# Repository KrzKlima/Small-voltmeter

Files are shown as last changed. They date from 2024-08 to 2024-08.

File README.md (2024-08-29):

# Small-voltmeter
The project and all files in this repository are provided under CC BY-NC-SA 4.0 license.

This voltmeter is small (I mean, small), cute, fits on a breadboard and is powered from a 3v3 voltage supply. It even includes a Zener voltage regulator, but for larger supply voltages a dropper resistor is required (0402 resistors have weak power capabilities). The use of bubble display makes reading the voltage easy, despite the minute size of the digits. It uses ATTiny44A and MCP3421 ADC. The board size is 20.5mm by 10.5mm. The device is able to measure its own supply voltage, so no such problems occur as in ICL7107 circuits.

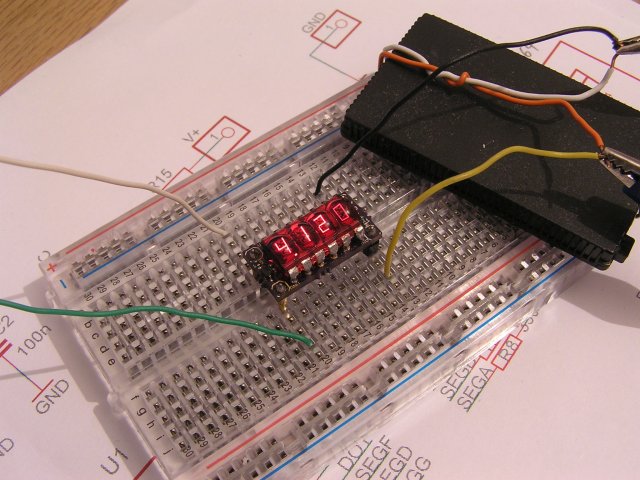
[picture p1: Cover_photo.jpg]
cover photo


The measurement ranges are the following:
1) -2V to 10V with the resolution of 1mV
2) outside the range 1), within -20 to 100V, with the resolution of 10mV
3) outside the ranges 1) and 2), within -200 to 200V, with the resolution of 100mV
(but you need to observe the safety issues with such high voltages)

Highlights:
- small form factor ~DIP16
- due to the low pin count of the MCU, I2C bus to the external ADC is multiplexed with display outputs - and it still works!
- differential input
- measures ground referenced voltages of both polarities

Two videos showing the operation of the multimeter are linked below.

SAMPLE VIDEO 1 (https://www.youtube.com/watch?v=5PMVABGqFHo "Small multimeter - video 1")
SAMPLE VIDEO 2 (https://www.youtube.com/watch?v=kH4eJVx0Qz0 "Small multimeter - video 2")

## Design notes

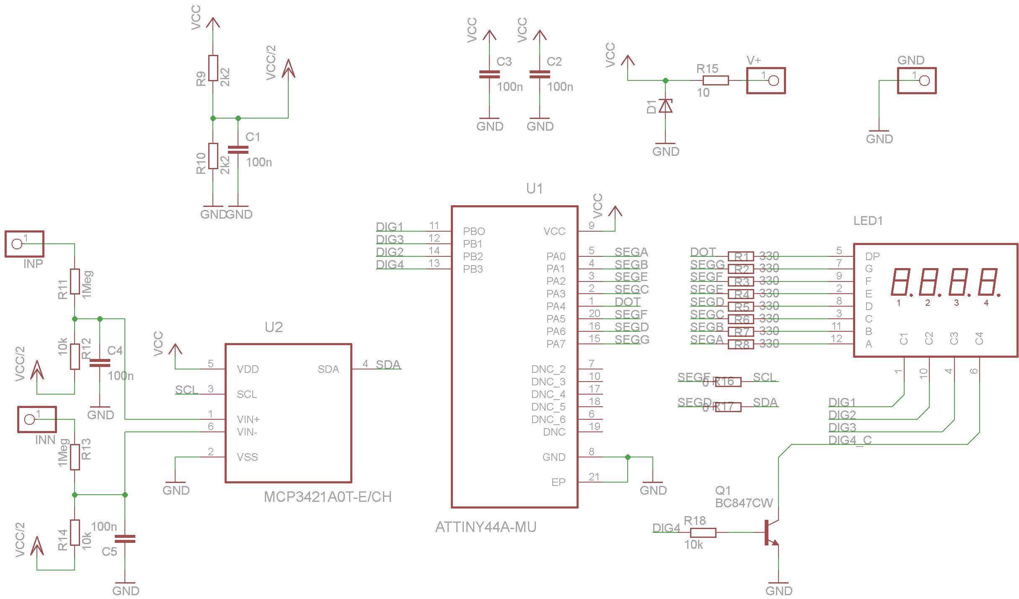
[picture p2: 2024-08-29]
PCB/maly_woltomierz_schemat.png

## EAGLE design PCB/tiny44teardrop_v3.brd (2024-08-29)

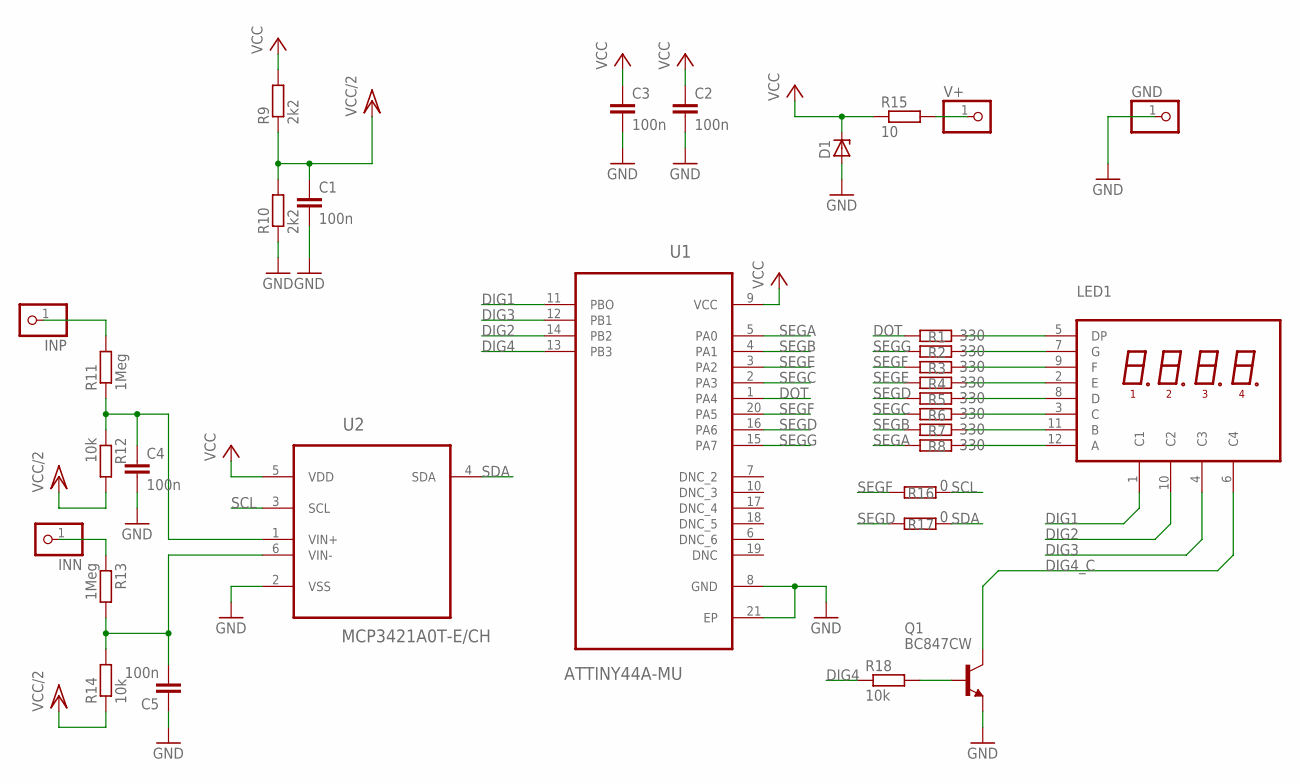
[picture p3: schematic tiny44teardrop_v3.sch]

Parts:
C1, C2, C3, C4, C5: 100n; C0603K
D1: BZX84CSMDBZT52C3V3S-7-F; SOD323-R
GND: PINHD-1X1; 1X01
INN: PINHD-1X1; 1X01
INP: PINHD-1X1; 1X01
LED1: 5082-7414
Q1: BC847CW; SOT323-BEC
R1, R2, R3, R4, R5, R6, R7, R8: 330; R0402
R9, R10: 2k2; R0402
R11, R13: 1Meg; R0603
R12, R14, R18: 10k; R0402
R15: 10; R0402
R16, R17: 0; R0402
U1: ATTINY44A-MU; QFN50P400X400X80-21N
U2: MCP3421A0T-E/CH; SOT95P270X145-6N
V+: PINHD-1X1; 1X01

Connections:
DIG1: LED1.1 (C1), U1.11 (PBO)
DIG2: LED1.10 (C2), U1.14 (PB2)
DIG3: LED1.4 (C3), U1.12 (PB1)
DIG4: R18.1, U1.13 (PB3)
DIG4_C: LED1.6 (C4), Q1.C
DOT: R1.1, U1.1 (PA4)
GND: C1.2, C2.2, C3.2, C4.2, C5.1, D1.A, GND.1, Q1.E, R10.1, U1.8 (GND), U1.21 (EP), U2.2 (VSS)
unnamed: LED1.5 (DP), R1.2
unnamed: LED1.7 (G), R2.2
unnamed: R15.2, V+.1
unnamed: LED1.2 (E), R4.2
unnamed: LED1.9 (F), R3.2
unnamed: LED1.3 (C), R6.2
unnamed: LED1.11 (B), R7.2
unnamed: LED1.12 (A), R8.2
unnamed: LED1.8 (D), R5.2
unnamed: INP.1, R11.2
unnamed: Q1.B, R18.2
unnamed: INN.1, R13.1
unnamed: C5.2, R13.2, R14.2, U2.6 (VIN-)
unnamed: C4.1, R11.1, R12.1, U2.1 (VIN+)
SCL: R16.1, U2.3 (SCL)
SDA: R17.1, U2.4 (SDA)
SEGA: R8.1, U1.5 (PA0)
SEGB: R7.1, U1.4 (PA1)
SEGC: R6.1, U1.2 (PA3)
SEGD: R5.1, R17.2, U1.16 (PA6)
SEGE: R4.1, U1.3 (PA2)
SEGF: R3.1, R16.2, U1.20 (PA5)
SEGG: R2.1, U1.15 (PA7)
VCC: C2.1, C3.1, D1.C, R9.2, R15.1, U1.9 (VCC), U2.5 (VDD)
VCC/2: C1.1, R9.1, R10.2, R12.2, R14.1

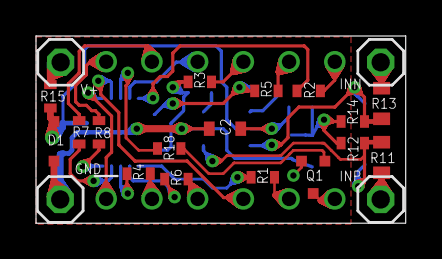
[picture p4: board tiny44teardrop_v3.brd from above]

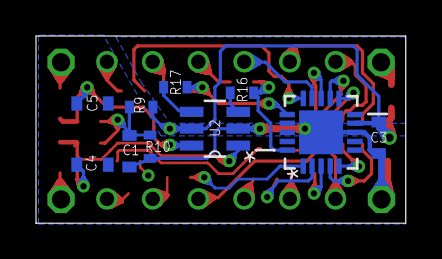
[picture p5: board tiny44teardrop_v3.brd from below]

Board: 2 copper layers, 20.5 x 10.4 mm, 32 parts (10 on the bottom side), 32 nets.

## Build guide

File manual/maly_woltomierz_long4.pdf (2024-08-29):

# Miniwoltomierz

### SQ3NQJ

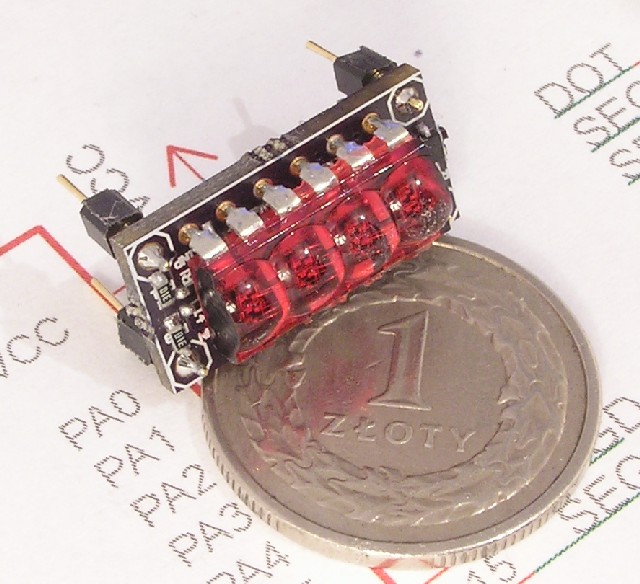
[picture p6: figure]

Układ służy do pomiaru napięcia, wykorzystuje niewielką liczbę komponentów i cechuje się niezwykle małymi rozmiarami. Zmierzoną wartość napięcia wyświetla za pomocą miniaturowych siedmiosegmentowych wyświetlaczy LED. Stopień podziału w dzielniku wejściowym jest zaprojektowany tak, aby prezentowany woltomierz można było wykorzystać do pomiaru napięć stałych w zakresie od -200V do +200V. Pomimo tego, ze względu na budowę urządzenia i bezpieczeństwo jego użytkowania zakres bezpiecznie mierzonych napięć jest mniejszy i ograniczony względami bezpieczeństwa użytkownika. Różnicowa impedancja wejściowa wynosi około 2MΩ.

Układ wykonany jest w technologii montażu powierzchniowego, wykorzystuje jedynie dwa układy scalone: mikrokontroler oraz przetwornik analogowo-cyfrowy. Pozostałe elementy to 1 tranzystor, dioda Zenera i rezystory oraz kondensatory.
Schemat blokowy układu przedstawiony jest na rysunku 1, a dokładny schemat ideowy przedstawiony jest na rysunku 3 na końcu dokumentu. Spis elementów zamieszczony jest w tabeli 1 na końcu dokumentu.

Rysunek 1. Schemat blokowy woltomierza.

Zastosowanie niewielkich elementów i ograniczenie ich liczby umożliwiło spektakularne zmniejszenie całości urządzenia do wymiarów 20,5mm na 10,5mm i wysokość, po zamontowaniu na płytce stykowej, 11mm. Widok projektu płytki przedstawiony jest na rysunku 8.
Na rysunku 2 pokazane jest urządzenie w trakcie pomiarów. Uwagę zwracają małe wymiary. Wyświetlacz jest czytelny nawet przy dużych kątach obserwacji.

dzielnik
rezystorowy

ADC

(MCP3421) | ATTiny44a | wyświetlacz LED

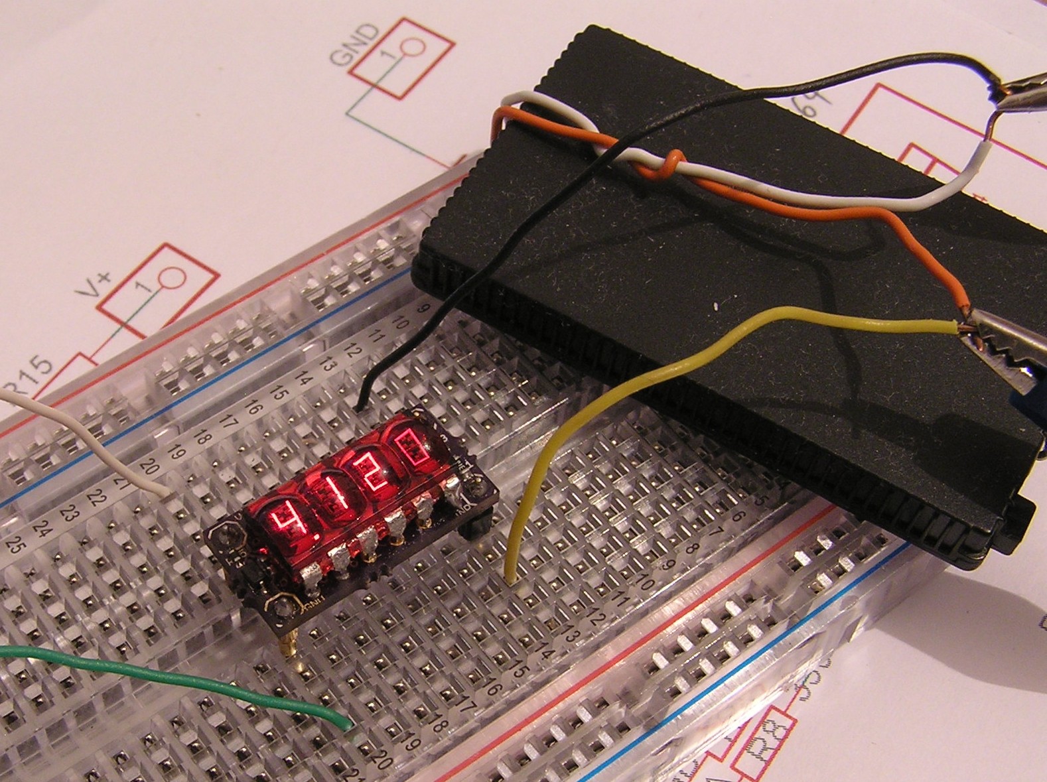
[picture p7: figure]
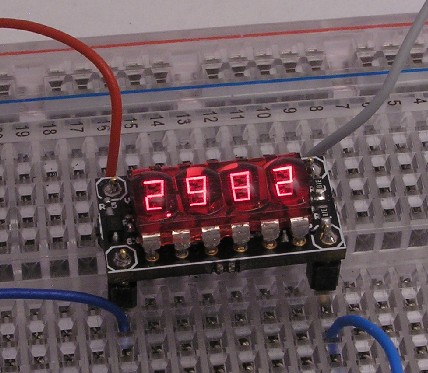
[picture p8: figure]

Rysunek 2. Woltomierz mierzący różne napięcia.

### Rozwiązania układowe

Woltomierz ma wejście różnicowe, umożliwia pomiar napięć zewnętrznych jak też własnego napięcia zasilania (przy dowolnej polaryzacji wejść). W układzie wykorzystywany jest przetwornik analogowo-cyfrowy o rozdzielczości 18 bitów, komunikujący się z mikrokontrolerem sterującym za pomocą magistrali I²C. Urządzenie pracuje poprawnie z układami MCP 3421 o dowolnym spośród 8 dostępnych adresów, ustawianych na etapie produkcji układu. Dzięki temu możliwe jest wykorzystanie dowolnej aktualnie dostępnej wersji tego przetwornika.
Ze względu na niewielką liczbę dostępnych wyprowadzeń, konieczne stało się wykorzystanie do podłączenia linii SDA i SCL interfejsu I²C wyprowadzeń używanych do sterowania wyświetlaczem. Jest to możliwe dzięki zapewnieniu poniższych warunków:
1. Transmisja odbywa się w czasie przerwy w wyświetlaniu danych na wyświetlaczu (wszystkie segmenty wszystkich cyfr są wtedy wygaszone) i nie jest przerywana aż do zakończenia transmisji.
2. Warunek startu i końca transmisji na liniach interfejsu występuje jedynie w chwilach rozpoczęcia i zakończenia transmisji I²C, a nie występuje w czasie wyświetlania danych na wyświetlaczu.

Wynik pomiaru wyświetlany jest na wyświetlaczu czteropozycyjnym bez dodatkowego znaku „minus”. Do wyświetlania znaku „minus” wykorzystywany jest jeden z segmentów wyświetlacza odpowiadającego „najstarszej” cyfrze. Takie rozwiązanie upraszcza konstrukcję i umożliwia wykorzystanie łatwiej dostępnych elementów, jednak ogranicza rozdzielczość wyświetlania dla wartości ujemnych. Zastosowane rozwiązanie umożliwia uzyskanie następujących rozdzielczości:

1) dla zakresu od -2V do 10V: 1mV
2) poza zakresem 1), dla zakresu od -20 do 100V: 10mV
3) poza zakresami 1) i 2), dla zakresu od -200 do 200V: 100mV

Układ zasilany jest napięciem 3,3V. Układ wyposażony jest w prosty stabilizator napięcia zasilania z diodą Zenera, zapewniający podstawowe zabezpieczenie przed zbyt wysokim napięciem zasilania, bądź odwrotnym podłączeniem napięcia zasilającego. Pobór prądu wynosi około 24mA – większość prądu zużywana jest przez wyświetlacz LED.
Aby umożliwić pomiar napięć o dowolnej polaryzacji, zastosowane zostało bardzo proste rozwiązanie, polegające na użyciu potencjału masy pozornej – elementy R9, R10, C1 – jako potencjału odniesienia dla dzielników wejściowych. Konsekwencją tego jest utrzymywanie potencjału spoczynkowego wejść woltomierza na poziomie zbliżonym do połowy napięcia zasilania mierzonym względem masy zasilania woltomierza. Jednak wysoka impedancja wejściowa woltomierza zmniejsza wpływ tego napięcia na badany układ.
Dziwić może obecność tranzystora Q1, okazał się on jednak niezbędny ze względu na znacznie mniejszą wydajność prądową bufora wyjściowego pinu PB3 (pracującego domyślnie jako nóżka RESET) w porównaniu z pozostałymi pinami mikrokontrolera.

### Oprogramowanie

W większości urządzeń zawierających układy programowalne, o funkcjonalności urządzenia decyduje w głównej mierze oprogramowanie. Podobnie jest w tym przypadku. Uproszczony schemat blokowy działania oprogramowania przedstawiony jest na rysunku 4.
Po rozpoczęciu działania urządzenia inicjalizowane są porty mikrokontrolera i wyszukiwany jest adres I²C przetwornika analogowo-cyfrowego, następnie dokonywane jest sprawdzenie, czy dokonana została poprawna kalibracja lub czy należy zresetować ustawienia kalibracyjne. W przypadku braku danych kalibracyjnych uruchamiana jest procedura kalibracji, opisana dalej. W przypadku odnalezienia w pamięci EEPROM poprawnych danych kalibracyjnych urządzenie przechodzi w tryb pomiaru napięcia. W nieskończonej pętli urządzenie cyklicznie pobiera dane z przetwornika, poddaje je odpowiednim przeliczeniom i umieszcza dane wynikowe w pamięci. Z pamięci dane te są z kolei pobierane przez procedurę obsługi wywoływanego około 500 razy na sekundę przerwania wyświetlającego wyniki pomiaru na czteropozycyjnym wyświetlaczu siedmiosegmentowym. Warto podkreślić, że na czas trwania komunikacji z przetwornikiem analogowo-cyfrowym, ze względu na fakt podwójnego wykorzystania linii danych i zegara I²C, przerwanie odpowiadające za obsługę wyświetlacza jest blokowane, aby nie zakłócić transferu danych.
Dla najniższego zakresu pomiarowego, charakteryzującego się największą rozdzielczością, zmieniane jest ustawienie wzmacniacza pomiarowego znajdującego się wewnątrz przetwornika analogowo-cyfrowego. Wzmocnienie ustawiane jest na 2V/V, zamiast wykorzystywanego w pozostałych zakresach 1V/V. Użycie wzmocnienia 2V/V jest niezbędne w celu zapewnienia faktycznej rozdzielczości woltomierza wynoszącej dla najniższego zakresu 1mV.

### Procedura kalibracji

Kalibracja przeprowadzana jest z wykorzystaniem zewnętrznego napięcia o wartości 10V. W przypadku wykrycia braku poprawnych wartości kalibracyjnych uruchamiana jest procedura kalibracji, w której program dokonuje wielokrotnego pomiaru podawanego napięcia i uśrednia wynik. Następnie sprawdzane jest, czy otrzymana wartość kalibracyjna mieści się w założonych granicach. Dzięki temu możliwe jest uniknięcie większości przypadków niepoprawnie przeprowadzonej kalibracji. Kalibracja przeprowadzana jest dla 2 różnych ustawień wzmacniacza o regulowanym wzmocnieniu, znajdującego się wewnątrz przetwornika MCP3421. Prowadzona jest odrębna kalibracja dla wzmocnienia 1V/V i 2V/V, jedna po drugiej. W pierwszej kolejności kalibrowane jest wzmocnienie 1V/V, po czym wyświetlana jest wartość kalibracyjna. Następnie wyświetlacz jest wyłączany i przeprowadzana jest kalibracja dla wzmocnienia 2V/V, po zakończeniu której wyświetlana jest wartość kalibracyjna. W tym momencie konieczne jest wyłączenie zasilania woltomierza. Po ponownym jego włączeniu układ powinien przystąpić do dokonywania normalnych pomiarów.

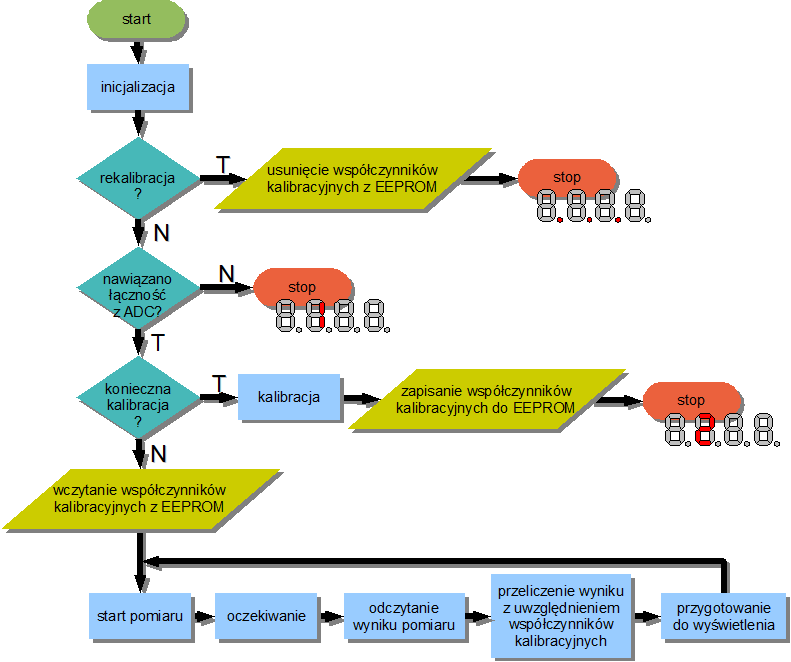
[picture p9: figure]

Rysunek 4. Schemat działania oprogramowania.

### Konstrukcja

Na początkowym etapie konstrukcji konieczne jest zadecydowanie, jakie napięcie wykorzystywane będzie do zasilania woltomierza. W układzie zawarty jest bowiem prosty układ stabilizatora (elementy D1, R15). W modelowym egzemplarzu przewidziano zasilanie napięciem 3,3V. W przypadku wykorzystania innego napięcia zasilania (jednak nie niższego niż około 2,7V), konieczne jest zastosowania rezystora R15 o innej wartości. Dla napięć niższych niż 3,3V może on zachować wartość 10 omów, jednak dla napięć wyższych konieczne jest wyliczenie jego wartości za pomocą przybliżonego wzoru zamieszczonego poniżej:

R15=
U zasilania−3,3V
40mA

10

Warto w w tym momencie podkreślić, że zastosowane w układzie rezystory o rozmiarze 0402 mają bardzo ograniczoną maksymalną moc strat, około 60mW. Nie można zatem przekroczyć wartości napięcia zasilania skutkującej wydzieleniem takiej mocy na rezystorze R15. Wydzielaną moc

wyznacza się ze wzoru:

PR15=

U zasilania−3,3V

2
R15

W

Oznacza to, że w praktyce maksymalne napięcie zasilania (przy użyciu rezystora R15 o odpowiedniej wartości) nieznacznie przekracza 5V. W celu zastosowania napięcia zasilania o większej wartości, należy szeregowo z układem włączyć rezystor o odpowiedniej wartości rezystancji i mocy.
W dalszej kolejności należy wlutować elementy, schemat montażowy widoczny jest na rysunku
9. Zalecane jest rozpoczęcie od wlutowania mikrokontrolera w obudowie QFN i sprawdzenie poprawności podłączeń. Najwygodniej chyba wlutować układ z użyciem pasty lutowniczej i lutownicy na gorące powietrze do przylutowania środkowego pada, a następnie używając cienkiej cyny i topnika w dużej ilości przylutować 20 wyprowadzeń mikrokontrolera. Nieuchronny w takim wypadku nadmiar cyny należy zebrać za pomocą plecionki. Metoda taka okazuje się w warunkach amatorskich bardziej niezawodna niż lutowanie mikrokontrolera wyłącznie pastą lutowniczą i lutownicą na gorące powietrze, ze względu na trudność w dozowaniu pasty i powstające w wyniku tego zwarcia pod spodem obudowy mikrokontrolera. Problemów takich da się zapewne uniknąć przy wykorzystaniu odpowiedniego sita do nakładania pasty lutowniczej.
Po weryfikacji poprawności lutowania mikrokontrolera należy wlutować pozostałe elementy za wyjątkiem wyświetlacza, zworek R16, R17 i rezystora R18. Do padu rezystora R18 położonego bliżej mikrokontrolera należy wlutować krótki odcinek kynaru lub innego cienkiego drutu – będzie on niezbędny w procesie programowania (patrz rysunek 5).

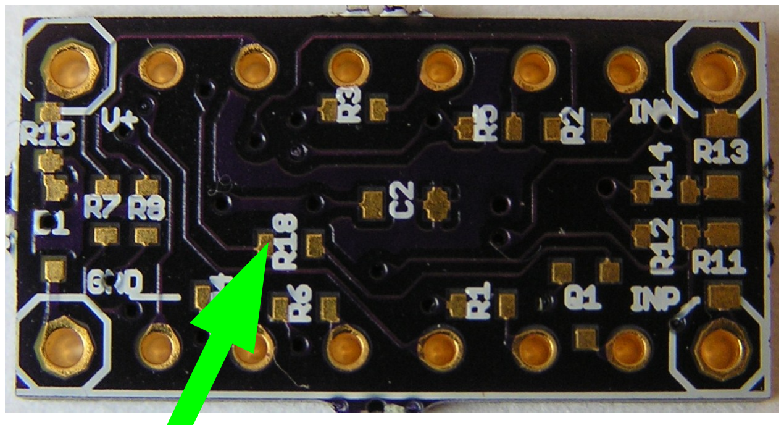
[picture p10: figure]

Rysunek 5. Miejsce lutowania drutu RESET

W kolejnym kroku należy podłączyć programator ISP – nóżki MISO, MOSI, SCK do odpowiednich pól lutowniczych przygotowanych dla wyświetlacza, RESET do wspomnianego wcześniej drucika oraz VCC i GND do szyn zasilania. Pomocny może się tu okazać sposób podłączenia za pomocą 18 pinowej podstawki pod układy DIP oraz goldpinów dociskających, jak zostało to pokazane na rysunku 6.

UWAGA!
W oryginalnym rozwiązaniu Atmela pin oznaczony jako VCC w złączu programatora jest WEJŚCIEM programatora i służy do mierzenia napięcia zasilania i odpowiedniego wysterowania buforów programatora. Zastosowanie wynalazków „dostarczających zasilanie do programowanego układu” podających 5V na tym pinie może (choć nie powinno w krótkim czasie) skutkować uszkodzeniem programowanego urządzenia lub programatora.

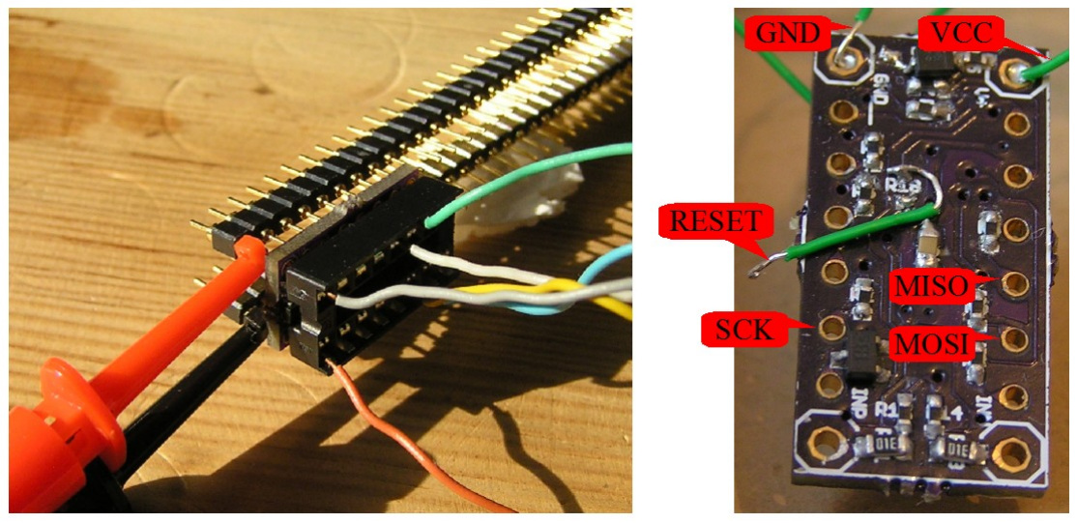
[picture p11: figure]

Rysunek 6. Podłączenie programatora ISP. Chwytaki dostarczają zasilanie do układu.

Po poprawnym zaprogramowaniu (z weryfikacją) pamięci programu oraz pamięci EEPROM mikrokontrolera, należy przystąpić do zmiany ustawień fusebitów. Należy zaprogramować:
– układ brownout na napięcie 2,7V – nie jest to ustawienie domyślne, trzeba zmienić,
– zegar na wewnętrzny – jest to ustawienie domyślne – nie trzeba zmieniać,
– podział zegara przez 8 (CKDIV8) – jest to ustawienie domyślne – nie trzeba zmieniać,
– wyłączyć obwód zewnętrznego resetu (RSTDISBL) – nie jest to ustawienie domyślne, trzeba zmienić, patrz punkt „UWAGA!” niżej.

UWAGA!
Po tym kroku ponowne przeprogramowanie za pomocą programatora ISP będzie niemożliwe, konieczne będzie użycie programatora wysokonapięciowego (na przykład AVR Dragon). Urządzenie nie jest jednak przystosowane do podłączania programatora wysokonapięciowego. Należy zatem dokładnie sprawdzić poprawność wszystkich ustawień przed zaprogramowaniem fusebitów.

Można również zaprogramować bit EESAVE, zapobiegający czyszczeniu pamięci EEPROM w razie przeprogramowywania układu. Pozostałe fusebity należy pozostawić bez zmian. Ostatecznie należy zaprogramować poniższe wartości fusebitów (rysunek 7).

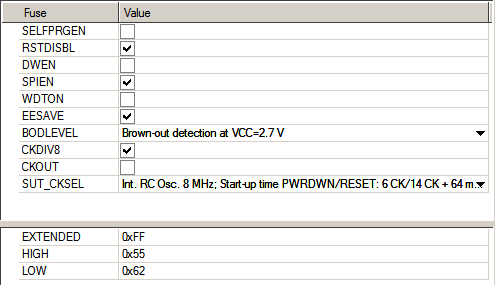
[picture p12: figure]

Rysunek 7. Ustawienia fusebitów (AVR Studio 4)

Kolejno należy wlutować wyświetlacz oraz zworki R16, R17 i rezystor R18 i skontrolować wszystkie połączenia.

Jeśli montaż i programowanie przeprowadzone były poprawnie, można włączyć zasilanie, nie podłączając żadnego napięcia wejściowego. Po pewnym czasie (kilkanaście sekund) na wyświetlaczu powinien pojawić się kod błędu 2, oznaczający niepoprawnie przeprowadzoną kalibrację. Należy wtedy odłączyć zasilanie, podłączyć napięcie kalibrujące 10V (użyłem układu LT1019-10) – uwaga na poprawną polaryzację napięcia kalibrującego – i ponownie włączyć zasilanie. Kolejno zmierzone i pokazane na wyświetlaczu zostaną 2 wartości kalibracyjne w następującej sekwencji:

1. wyświetlacze wygaszone (kilka sekund),
2. wyświetlanie wartości kalibracyjnej dla wzmocnienia 1V/V (kilka sekund),
3. wyświetlacze wygaszone (kilka sekund),
4. wyświetlanie wartości kalibracyjnej dla wzmocnienia 2V/V (ciągłe).

Wyznaczone wartości zostaną automatycznie zapamiętane w pamięci EEPROM. Należy teraz wyłączyć zasilanie i włączyć je ponownie. Układ powinien teraz przystąpić do normalnej pracy i wyświetlać wartość mierzonych napięć.

### Kody błędów i komunikaty

W trakcie uruchamiania pojawić się mogą błędy lub komunikaty, sygnalizowane na wyświetlaczu. Poniżej pokazane zostały kody i prawdopodobne przyczyny wystąpienia oraz znaczenie komunikatów.

Wyświetlacz | Znaczenie
| Błąd komunikacji z przetwornikiem ADC. Prawdopodobne przyczyny: • nieprawidłowo wlutowane zworki R16 i/lub R17, • nieprawidłowo wlutowany układ MCP3421, • nieprawidłowo wlutowany układ ATTiny44a (zwarcia, brak kontaktu).
| Błąd kalibracji. Prawdopodobne przyczyny: • podanie błędnego napięcia kalibrującego (powinno być dokładnie 10V) w trakcie pierwszego uruchomienia bądź po rekalibracji, • odwrotne podłączenie napięcia kalibrującego, • błąd montażu obwodów wejściowych, • złe wartości rezystorów, • źle wykonane połączenia w dzielniku wejściowym.
| Komunikat o usunięciu danych kalibracyjnych. W trakcie kolejnego urucho-mienia konieczna rekalibracja. Prawdopodobne przyczyny, jeśli nie jest to pożądane zachowanie: • zwarcie PA0 z masą.

### Obsługa

W celu skasowania wartości kalibracyjnych i ponownego przeprowadzenia procesu kalibracji, należy przed włączeniem zasilania zewrzeć pin PA0 (lub, prościej, nóżkę 12 wyświetlacza) z masą układu po czym włączyć zasilanie. Na wyświetlaczu pojawią się kropki. Teraz należy odłączyć zasilanie. Przy kolejnym włączeniu konieczne będzie przeprowadzenie kalibracji.
Urządzenie powinno być utrzymywane w czystości i nie powinno być bezpośrednio dotykane palcami od spodniej strony – docierające z dzielnika do przetwornika napięcia są małe i zanieczyszczenia powodują duże zakłócenia odczytu. Zmiana wyświetlanej wartości o 1mV na najniższym zakresie oznacza zmianę napięcia wyjściowego z dzielnika o około 10μV.

### Zmierzone osiągi

Wykorzystując posiadany sprzęt pomiarowy, oszacowałem, że dokładność pomiaru napięcia przy poprawnej kalibracji mieści się w zakresie poniżej ±1%. Ze względu na zastosowanie w dzielniku napięcia wejściowego rezystorów o dokładności 1% bez ich dobierania, układ charakteryzuje się wrażliwością na napięcie współbieżne podawane na wejścia różnicowe. Wpływ napięcia współbieżnego, mierzonego względem masy układu, na pomiar oszacowany został w egzemplarzu modelowym na około 2mV/V.
Podsumowując – układ jest prostym i nieskomplikowanym woltomierzem napięcia stałego, okazał się być użytecznym narzędziem pozwalającym szybko (i z zadowalającą dokładnością i rozdzielczością) określić wartość napięcia w budowanym układzie. Koszt jednostkowy budowy (elementy, płytka) zamyka się w kwocie poniżej 50 zł.

Tabela 1. Spis elementów

Typ i wartość | Liczba | Obudowa | Numery części
Rezystor 0Ω | 2 | 0402 | R16, R17
Rezystor 10Ω | 1 | 0402 | R15
Rezystor 10kΩ | 3 | 0402 | R12, R14, R18
Rezystor 1MΩ | 2 | 0603 | R11, R13
Rezystor 2,2kΩ | 2 | 0402 | R9, R10
Rezystor 330Ω | 8 | 0402 | R1, R2, R3, R4, R5, R6, R7, R8
Kondensator 100nF | 5 | 0603 | C1, C2, C3, C4, C5
Dioda Zenera 3V3 | 1 | SOD-323 | D1
Mikrokontroler ATTINY44A-MU | 1 | QFN-20 | U1
Tranzystor BC847CW | 1 | SOT-323 | Q1
Przetwornik ADC MCP3421 | 1 | SOT-23-6 | U2
wyświetlacz LED QDSP-6064 | 1 | DIP12 | LED1

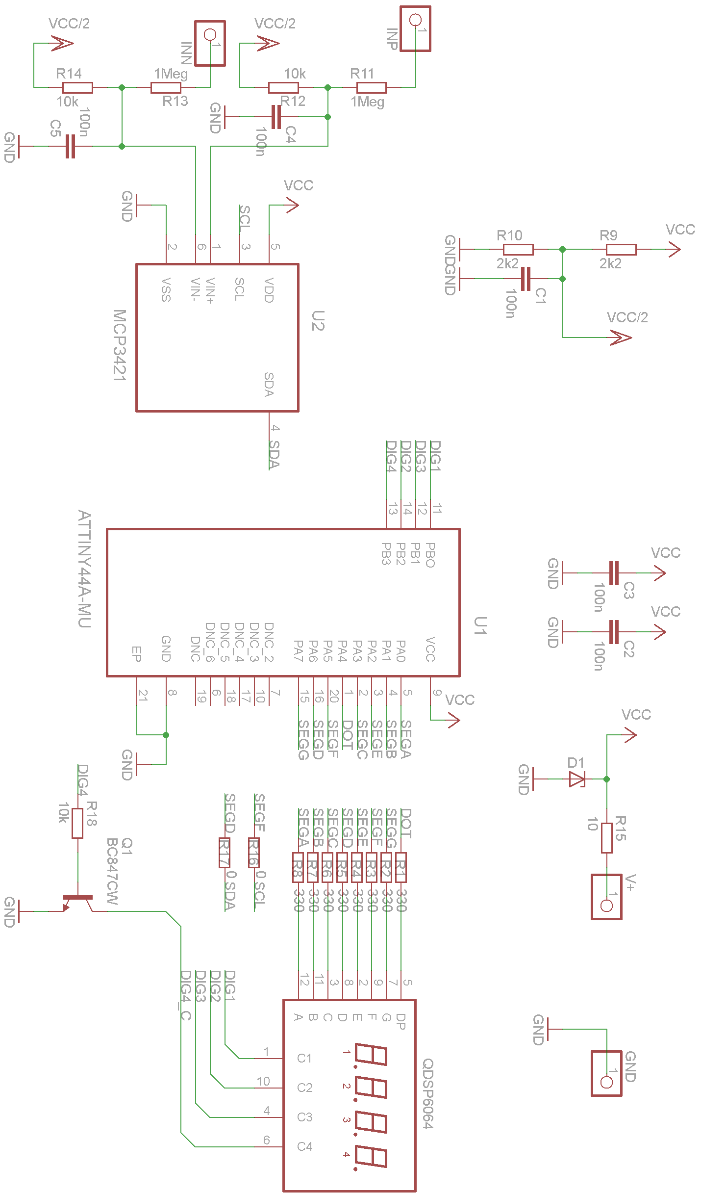
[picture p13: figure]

Rysunek 3. Schemat układu woltomierza

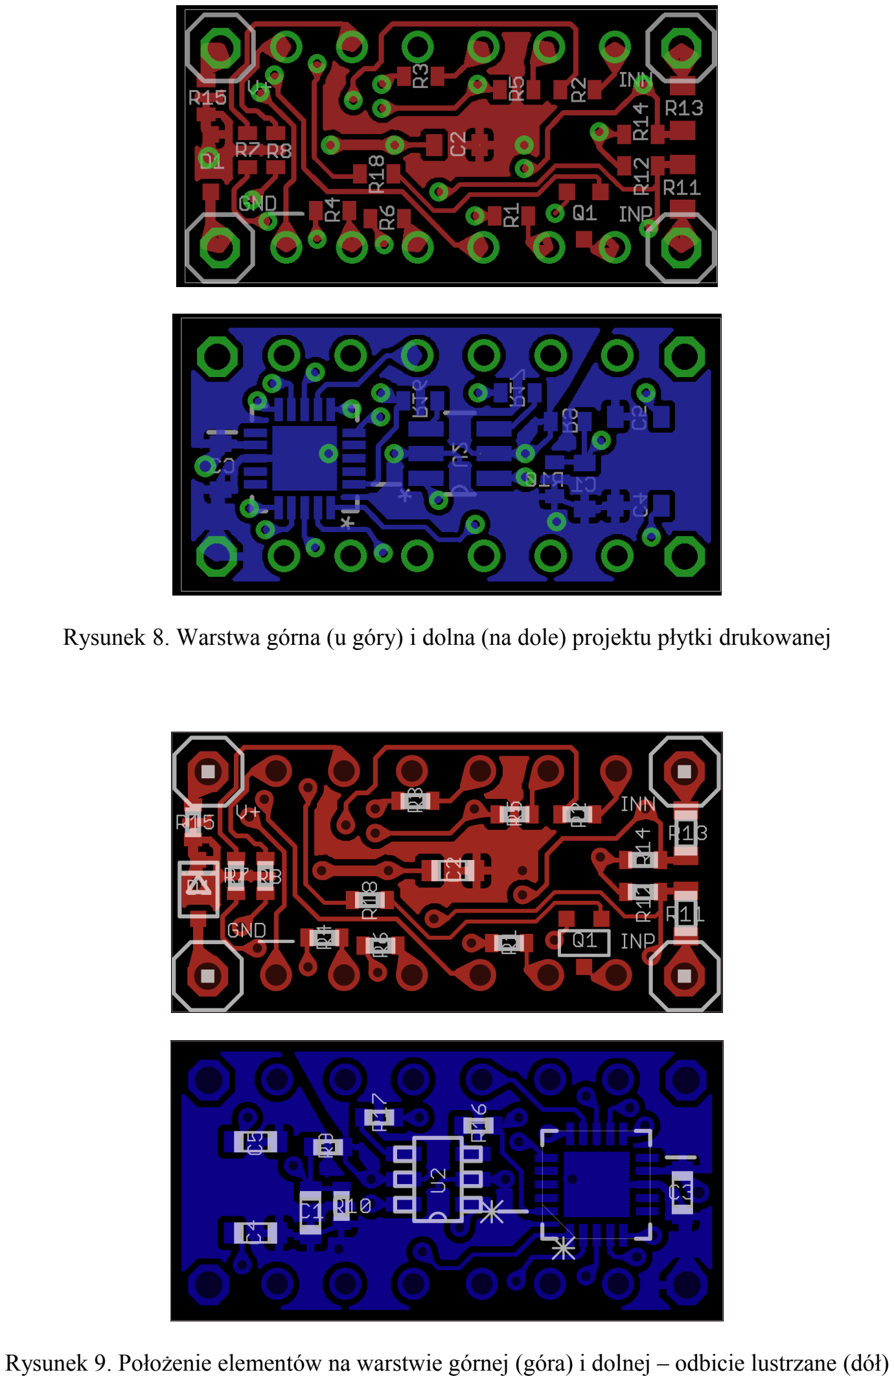
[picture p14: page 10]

Rysunek 8. Warstwa górna (u góry) i dolna (na dole) projektu płytki drukowanej

Rysunek 9. Położenie elementów na warstwie górnej (góra) i dolnej – odbicie lustrzane (dół)
